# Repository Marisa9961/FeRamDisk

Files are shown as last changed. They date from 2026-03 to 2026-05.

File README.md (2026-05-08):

# FeRamDisk: 基于 STM32G431 的铁电存储 U 盘

 
 
 


## 项目概述
FeRamDisk 是一款基于 **STM32G431** 主控与 **MB85RS256** 存储介质的专用闪存盘。

不同于传统的 NAND Flash 存储方案，本项目利用铁电随机存取存储器（FeRAM）的物理特性，实现了极高的读写耐久性与近乎瞬时的随机访问能力。

硬件设计中使用了四片并列的 **MB85RS256** ，单片容量为 32 kB（即 256 Kbit），总计达到的存储空间为 128 kB。

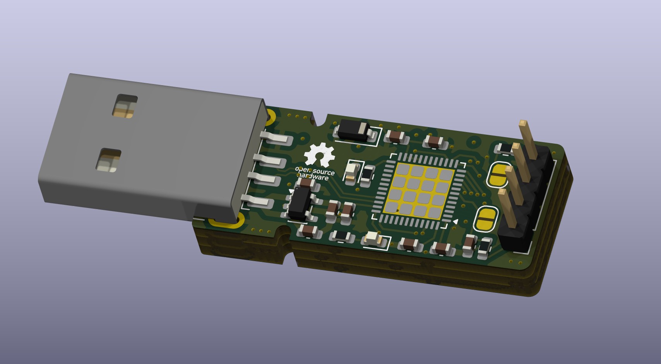
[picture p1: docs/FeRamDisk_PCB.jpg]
FeRamDisk_PCB


## 功能介绍

1. **硬件设计开源**：提供完整的 Kicad 工程、原理图及制造文件，可直接打板生产。
2. **USB 大容量存储设备固件设计**：基于 Rust embassy 异步框架，从零实现 SCSI 指令集与 BOT 协议，支持全平台免驱识别。
3. **影子存储区防止文件系统崩溃**：利用日志机制抽象存储操作，保障意外断电及插拔时的数据一致性。

## 快速上手

项目固件采用 Rust 编写。构建前请确保已安装 Rust 工具链。

```bash
cd firmware

# 编译固件（默认已启用 hardware feature）
cargo build --release

# 在主机上运行脱离硬件的单元测试（需关闭默认的硬件功能并指定主机平台）
# 另外需要根据自己的开发环境选择正确的目标平台
cargo test --no-default-features --target x86_64-pc-windows-msvc

# 如果已配置 probe-rs 等烧录工具，可直接一键编译并烧录
cargo run --release
```

## 项目构成

- `hardware/`: 硬件设计目录（包含 Kicad 源工程、BOM 表及 Gerber 生产文件）。
- `firmware/`: 核心固件目录（Rust 编写）。
  - `src/usb/`: USB 核心协议栈（MSC / BOT / SCSI）的具体实现。
  - `src/storage/`: 存储后端适配与事务日志系统（Journaling），确保块设备的高可靠读写。
  - `src/drivers/`: SPI 通信底漆及 MB85RS256 铁电存储芯片的驱动层。
  - `tests/`: 包含脱离硬件直接在 PC 端运行的协议栈软仿真测试环境。
- `docs/`: 相关的项目说明与文档资源。

## 贡献要点

欢迎任何形式的讨论与代码贡献（Pull Request / Issue）：
1. **固件开发**：PR 提交前，请确保能够通过 `tests/` 目录下的所有软仿真单元测试 (`cargo test`)。
2. **硬件优化**：如有 PCB 布局或元器件替代方案，请提供原因及 Kicad 源文件的修改。
3. **想法拓展**：欢迎探讨铁电特性（极快且无磨损限制）在微型数据记录器（Data Logger）等前沿领域的新用法。

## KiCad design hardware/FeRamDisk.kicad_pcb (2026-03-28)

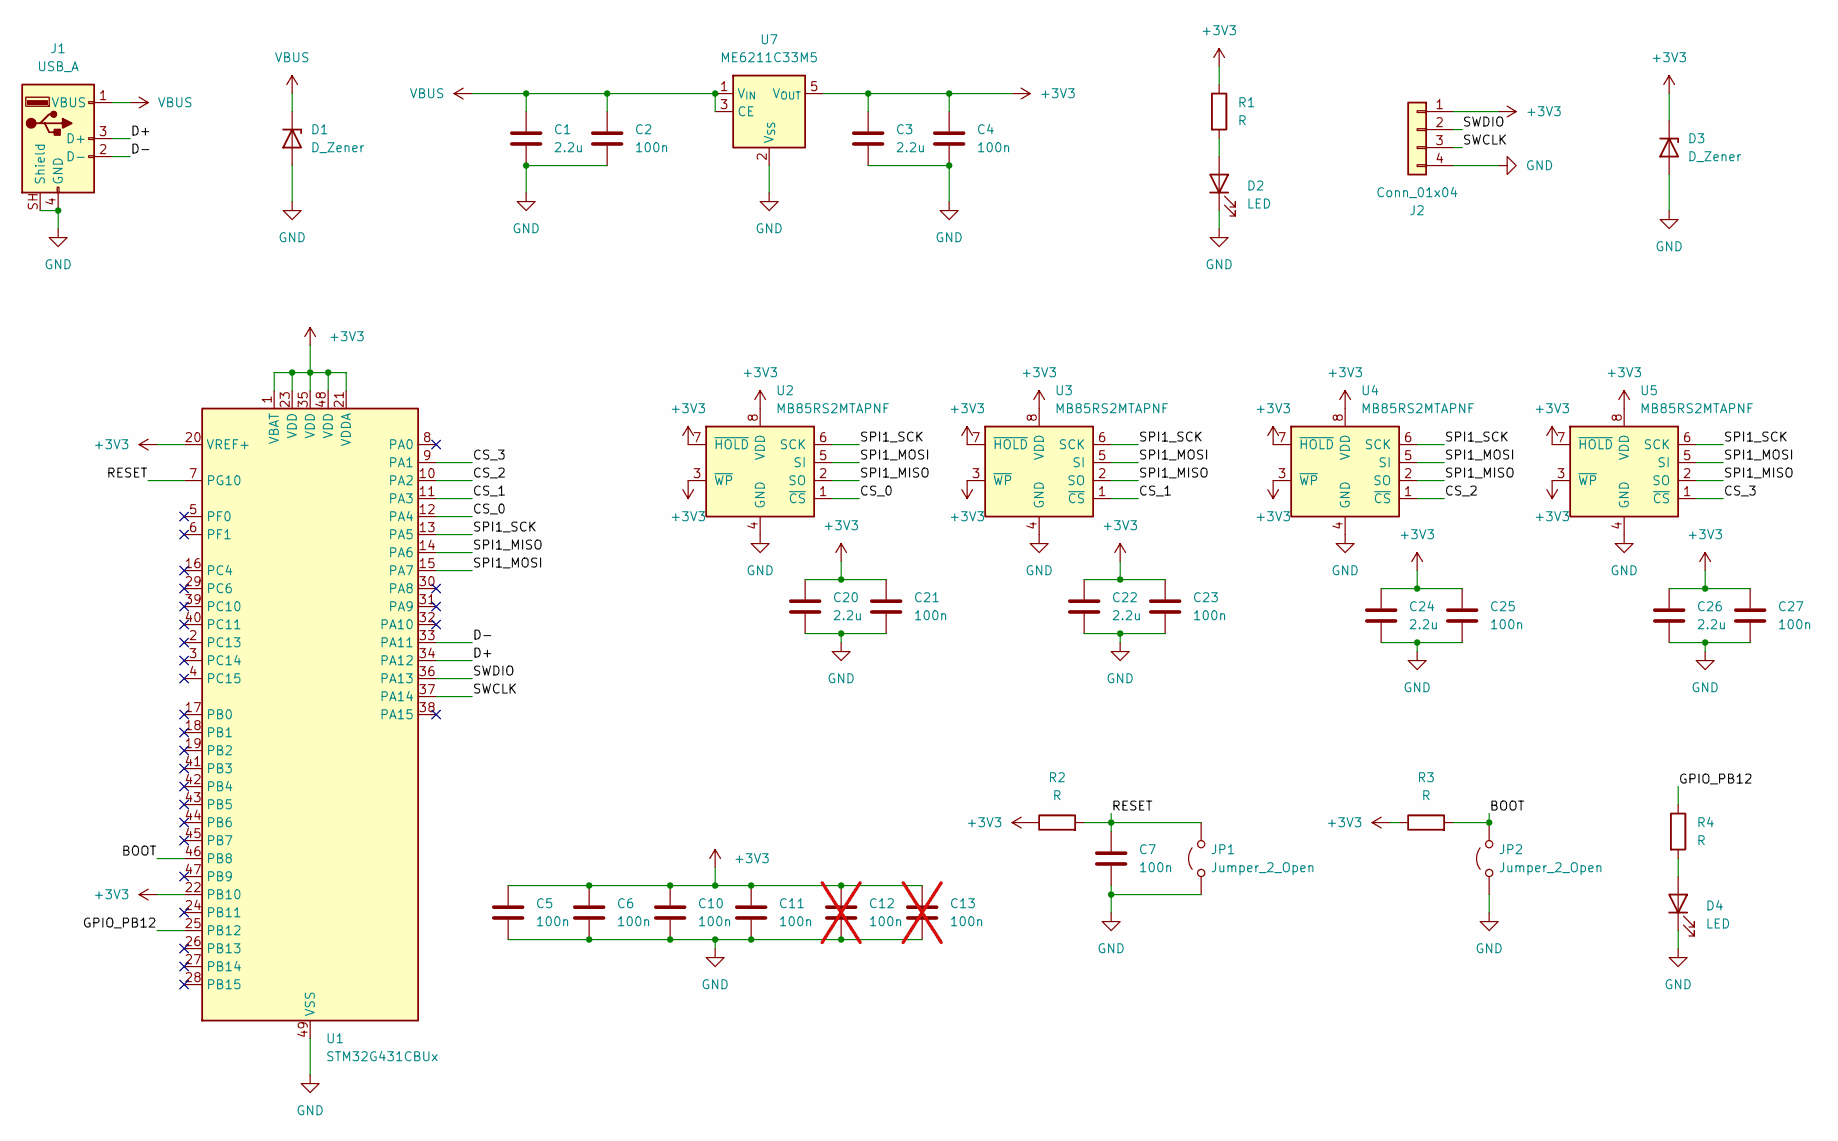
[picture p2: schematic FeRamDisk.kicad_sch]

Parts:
C1, C3, C20, C22, C24, C26: 2.2u; C_0603_1608Metric
C2, C4, C5, C6, C7, C10, C11, C21, C23, C25, C27: 100n; C_0603_1608Metric
C12, C13: 100n; C_0603_1608Metric; not fitted
D1, D3: D_Zener; D_SOD-123
D2, D4: LED; LED_0603_1608Metric
J1: USB_A; USB_A_CNCTech_1001-011-01101_Horizontal
J2: Conn_01x04; PinHeader_1x04_P2.54mm_Vertical
JP1, JP2: Jumper_2_Open; SolderJumper-2_P1.3mm_Open_RoundedPad1.0x1.5mm
R1, R2, R3, R4: R; R_0603_1608Metric
U1: STM32G431CBUx; QFN-48-1EP_7x7mm_P0.5mm_EP5.6x5.6mm
U2, U3, U4, U5: MB85RS2MTAPNF; SOP-8_3.76x4.96mm_P1.27mm
U7: ME6211C33M5; SOT-23-5

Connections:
+3V3: C3.1, C4.1, C5.1, C6.1, C10.1, C11.1, C12.1, C13.1, C20.1, C21.1, C22.1, C23.1, C24.1, C25.1, C26.1, C27.1, D3.1 (K), J2.1, R1.1, R2.1, R3.1, U1.1 (VBAT), U1.20 (VREF+), U1.21 (VDDA), U1.22 (PB10), U1.23 (VDD), U1.35 (VDD), U1.48 (VDD), U2.3 (~WP), U2.7 (~HOLD), U2.8 (VDD), U3.3 (~WP), U3.7 (~HOLD), U3.8 (VDD), U4.3 (~WP), U4.7 (~HOLD), U4.8 (VDD), U5.3 (~WP), U5.7 (~HOLD), U5.8 (VDD), U7.5 (V_{OUT})
/BOOT: JP2.2 (B), R3.2, U1.46 (PB8)
/CS_0: U1.12 (PA4), U2.1 (~CS)
/CS_1: U1.11 (PA3), U3.1 (~CS)
/CS_2: U1.10 (PA2), U4.1 (~CS)
/CS_3: U1.9 (PA1), U5.1 (~CS)
/D+: J1.3 (D+), U1.34 (PA12)
/D-: J1.2 (D-), U1.33 (PA11)
/GPIO_PB12: R4.1, U1.25 (PB12)
/RESET: C7.1, JP1.2 (B), R2.2, U1.7 (PG10)
/SPI1_MISO: U1.14 (PA6), U2.2 (SO), U3.2 (SO), U4.2 (SO), U5.2 (SO)
/SPI1_MOSI: U1.15 (PA7), U2.5 (SI), U3.5 (SI), U4.5 (SI), U5.5 (SI)
/SPI1_SCK: U1.13 (PA5), U2.6 (SCK), U3.6 (SCK), U4.6 (SCK), U5.6 (SCK)
/SWCLK: J2.3, U1.37 (PA14)
/SWDIO: J2.2, U1.36 (PA13)
GND: C1.2, C2.2, C3.2, C4.2, C5.2, C6.2, C7.2, C10.2, C11.2, C12.2, C13.2, C20.2, C21.2, C22.2, C23.2, C24.2, C25.2, C26.2, C27.2, D1.2 (A), D2.1 (K), D3.2 (A), D4.1 (K), J1.4 (GND), J1.SH (Shield), J2.4, JP1.1 (A), JP2.1 (A), U1.49 (VSS), U2.4 (GND), U3.4 (GND), U4.4 (GND), U5.4 (GND), U7.2 (V_{SS})
unnamed: D2.2 (A), R1.2
unnamed: D4.2 (A), R4.2
VBUS: C1.1, C2.1, D1.1 (K), J1.1 (VBUS), U7.1 (V_{IN}), U7.3 (CE)

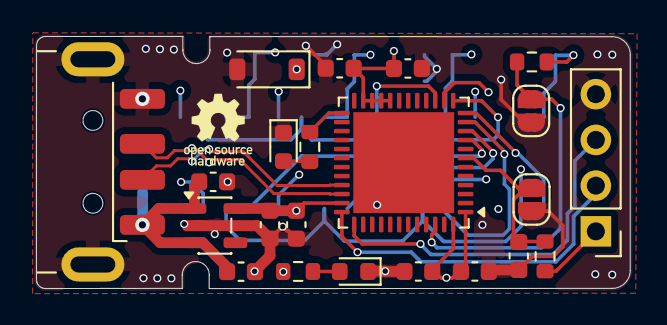
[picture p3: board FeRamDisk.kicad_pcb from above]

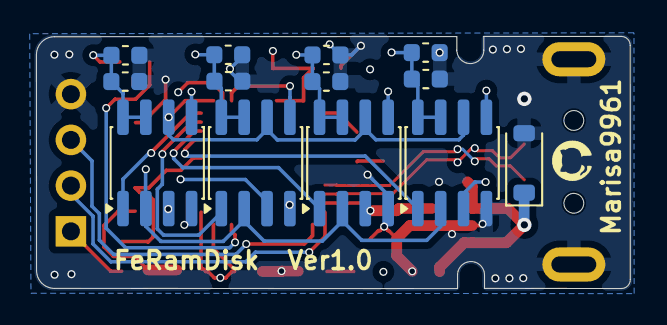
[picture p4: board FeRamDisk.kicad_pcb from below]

Board: 4 copper layers, 33.0 x 14.0 mm, 35 parts (13 on the bottom side), 19 nets.

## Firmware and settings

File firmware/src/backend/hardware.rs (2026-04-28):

use crate::drivers::feram::{self, FeRam};
use crate::drivers::spi::FramSpi;
use crate::init;
use crate::storage::{
    visible_block_count_from_physical,
    MetadataJournalStorage,
    JOURNAL_RESERVED_BLOCKS,
};
use embassy_stm32::gpio::{Level, Output, Speed};
use embassy_stm32::mode::Async;
use embassy_stm32::peripherals;
use embassy_stm32::spi::{self, mode::Master, Spi};
use embassy_stm32::time::Hertz;
use embassy_stm32::usb as stm32_usb;
use embassy_stm32::{Peri, Peripherals};
use rtt_target::rprintln;

pub type HardwareStorage = MetadataJournalStorage<
    FeRam<FramSpi<'static, Output<'static>, Output<'static>, Output<'static>, Output<'static>>>,
>;

#[derive(Debug, Copy, Clone, Eq, PartialEq)]
pub enum HardwareInitError {
    MissingResource(&'static str),
    VolumeInitFailed,
    JournalInitFailed,
}

pub struct HardwareParts {
    spi: Option<Spi<'static, Async, Master>>,
    cs0: Option<Output<'static>>,
    cs1: Option<Output<'static>>,
    cs2: Option<Output<'static>>,
    cs3: Option<Output<'static>>,
    usb: Option<Peri<'static, peripherals::USB>>,
    usb_dp: Option<Peri<'static, peripherals::PA12>>,
    usb_dm: Option<Peri<'static, peripherals::PA11>>,
}

fn spi_config() -> spi::Config {
    let mut config = spi::Config::default();
    config.frequency = Hertz(4_000_000);
    config
}

fn log_capacity(physical_blocks: u32, visible_blocks: u32) {
    rprintln!(
        "FeRAM capacity: physical={} blocks, visible={} blocks",
        physical_blocks,
        visible_blocks
    );
}

pub fn init_hardware_parts(p: Peripherals) -> HardwareParts {
    let spi = Spi::new(
        p.SPI1,
        p.PA5,
        p.PA7,
        p.PA6,
        p.DMA1_CH1,
        p.DMA1_CH2,
        init::Irqs,
        spi_config(),
    );

    let cs0 = Output::new(p.PA4, Level::High, Speed::VeryHigh);
    let cs1 = Output::new(p.PA3, Level::High, Speed::VeryHigh);
    let cs2 = Output::new(p.PA2, Level::High, Speed::VeryHigh);
    let cs3 = Output::new(p.PA1, Level::High, Speed::VeryHigh);

    HardwareParts {
        spi: Some(spi),
        cs0: Some(cs0),
        cs1: Some(cs1),
        cs2: Some(cs2),
        cs3: Some(cs3),
        usb: Some(p.USB),
        usb_dp: Some(p.PA12),
        usb_dm: Some(p.PA11),
    }
}

pub async fn init_storage(parts: &mut HardwareParts) -> Result<HardwareStorage, HardwareInitError> {
    let fram_spi = FramSpi::new(
        parts
            .spi
            .take()
            .ok_or(HardwareInitError::MissingResource("SPI already consumed"))?,
        parts
            .cs0
            .take()
            .ok_or(HardwareInitError::MissingResource("CS0 already consumed"))?,
        parts
            .cs1
            .take()
            .ok_or(HardwareInitError::MissingResource("CS1 already consumed"))?,
        parts
            .cs2
            .take()
            .ok_or(HardwareInitError::MissingResource("CS2 already consumed"))?,
        parts
            .cs3
            .take()
            .ok_or(HardwareInitError::MissingResource("CS3 already consumed"))?,
    );

    let mut fram = FeRam::new(fram_spi);
    let physical_blocks = fram.block_count();
    let visible_blocks = visible_block_count_from_physical(physical_blocks);

    log_capacity(physical_blocks, visible_blocks);

    for chip_idx in 0..feram::CHIP_COUNT {
        match fram.read_id(chip_idx).await {
            Ok(id) => {
                rprintln!(
                    "Chip {}: Device ID = 0x{:02X}{:02X}{:02X}",
                    chip_idx,
                    id[0],
                    id[1],
                    id[2]
                );
            }
            Err(e) => {
                rprintln!("Chip {}: ID read failed - {:?}", chip_idx, e);
            }
        }
    }

    match fram
        .ensure_mass_storage_volume_for_total_blocks_at_offset(visible_blocks, JOURNAL_RESERVED_BLOCKS)
        .await
    {
        Ok(true) => rprintln!("Initialized FAT12 volume for Windows"),
        Ok(false) => rprintln!("FAT12 volume already present"),
        Err(e) => {
            rprintln!("Volume initialization failed: {:?}", e);
            return Err(HardwareInitError::VolumeInitFailed);
        }
    }

    let mut storage = MetadataJournalStorage::new(fram);
    if let Err(e) = storage.initialize().await {
        rprintln!("Metadata journal initialization failed: {:?}", e);
        return Err(HardwareInitError::JournalInitFailed);
    }

    Ok(storage)
}

pub fn init_usb_driver(parts: &mut HardwareParts) -> Result<stm32_usb::Driver<'static, peripherals::USB>, HardwareInitError> {
    Ok(stm32_usb::Driver::new(
        parts
            .usb
            .take()
            .ok_or(HardwareInitError::MissingResource("USB peripheral already consumed"))?,
        init::Irqs,
        parts
            .usb_dp
            .take()
            .ok_or(HardwareInitError::MissingResource("USB DP already consumed"))?,
        parts
            .usb_dm
            .take()
            .ok_or(HardwareInitError::MissingResource("USB DM already consumed"))?,
    ))
}

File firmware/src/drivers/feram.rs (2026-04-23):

#![allow(dead_code)]

use core::cmp::min;

use crate::drivers::spi::{FramSpi, FramSpiError};
use embedded_hal::digital::OutputPin;

pub const BLOCK_SIZE: usize = crate::storage::BLOCK_SIZE;
pub const CHIP_COUNT: usize = 4;
pub const CHIP_SIZE_BYTES: usize = 32 * 1024;
pub const TOTAL_SIZE_BYTES: usize = CHIP_COUNT * CHIP_SIZE_BYTES;
pub const TOTAL_BLOCKS: u32 = (TOTAL_SIZE_BYTES / BLOCK_SIZE) as u32;

const PARTITION_START_BLOCK: u32 = 1;
const FAT_COUNT: u8 = 2;
const FAT12_MAX_CLUSTERS: u32 = 0x0FF4;
const ROOT_DIR_ENTRIES: u16 = 32;
const RESERVED_SECTORS: u16 = 1;
const PARTITION_TYPE_FAT12: u8 = 0x01;
const MEDIA_DESCRIPTOR: u8 = 0xF8;
const BOOT_OEM_NAME: &[u8; 8] = b"FRAMDISK";
const VOLUME_LABEL: &[u8; 11] = b"FERAMDISK  ";
const FILE_SYSTEM_TYPE: &[u8; 8] = b"FAT12   ";

#[derive(Copy, Clone)]
struct Fat12Geometry {
    sectors_per_cluster: u8,
    fat_sectors: u16,
    root_dir_sectors: u16,
}

const CMD_WREN: u8 = 0x06;
const CMD_WRDI: u8 = 0x04;
const CMD_RDSR: u8 = 0x05;
const CMD_WRSR: u8 = 0x01;
const CMD_READ: u8 = 0x03;
const CMD_FAST_READ: u8 = 0x0B;
const CMD_WRITE: u8 = 0x02;
const CMD_RDID: u8 = 0x9F;
const CMD_SLEEP: u8 = 0xB9;

#[derive(Debug, Copy, Clone, Eq, PartialEq)]
pub enum FeRamError<SpiError, CsError> {
    OutOfRange,
    Bus(crate::drivers::spi::FramSpiError<SpiError, CsError>),
}

pub struct FeRam<BUS> {
    bus: BUS,
}

impl<BUS> FeRam<BUS> {
    pub const fn new(bus: BUS) -> Self {
        Self { bus }
    }

    pub fn capacity_bytes(&self) -> usize {
        TOTAL_SIZE_BYTES
    }

    pub fn block_count(&self) -> u32 {
        TOTAL_BLOCKS
    }
}

impl<'d, CS0, CS1, CS2, CS3> FeRam<FramSpi<'d, CS0, CS1, CS2, CS3>>
where
    CS0: OutputPin,
    CS1: OutputPin<Error = CS0::Error>,
    CS2: OutputPin<Error = CS0::Error>,
    CS3: OutputPin<Error = CS0::Error>,
{
    pub async fn read(
        &mut self,
        address: usize,
        out: &mut [u8],
    ) -> Result<(), FeRamError<embassy_stm32::spi::Error, CS0::Error>> {
        self.check_range(address, out.len())?;

        let mut remaining = out;
        let mut current_addr = address;

        while !remaining.is_empty() {
            let chip = current_addr / CHIP_SIZE_BYTES;
            let chip_addr = (current_addr % CHIP_SIZE_BYTES) as u32;
            let chunk_len = min(CHIP_SIZE_BYTES - (current_addr % CHIP_SIZE_BYTES), remaining.len());

            let (chunk, tail) = remaining.split_at_mut(chunk_len);
            self.read_on_chip(chip, chip_addr, chunk).await?;

            current_addr += chunk_len;
            remaining = tail;
        }

        Ok(())
    }

    pub async fn fast_read(
        &mut self,
        address: usize,
        out: &mut [u8],
    ) -> Result<(), FeRamError<embassy_stm32::spi::Error, CS0::Error>> {
        self.check_range(address, out.len())?;

        let mut remaining = out;
        let mut current_addr = address;

        while !remaining.is_empty() {
            let chip = current_addr / CHIP_SIZE_BYTES;
            let chip_addr = (current_addr % CHIP_SIZE_BYTES) as u32;
            let chunk_len = min(CHIP_SIZE_BYTES - (current_addr % CHIP_SIZE_BYTES), remaining.len());

            let (chunk, tail) = remaining.split_at_mut(chunk_len);
            self.fast_read_on_chip(chip, chip_addr, chunk).await?;

            current_addr += chunk_len;
            remaining = tail;
        }

        Ok(())
    }

    pub async fn write(
        &mut self,
        address: usize,
        data: &[u8],
    ) -> Result<(), FeRamError<embassy_stm32::spi::Error, CS0::Error>> {
        self.check_range(address, data.len())?;

        let mut remaining = data;
        let mut current_addr = address;

        while !remaining.is_empty() {
            let chip = current_addr / CHIP_SIZE_BYTES;
            let chip_addr = (current_addr % CHIP_SIZE_BYTES) as u32;
            let chunk_len = min(CHIP_SIZE_BYTES - (current_addr % CHIP_SIZE_BYTES), remaining.len());

            let (chunk, tail) = remaining.split_at(chunk_len);
            self.write_on_chip(chip, chip_addr, chunk).await?;

            current_addr += chunk_len;
            remaining = tail;
        }

        Ok(())
    }

    pub async fn read_block(
        &mut self,
        block_index: u32,
        out: &mut [u8; BLOCK_SIZE],
    ) -> Result<(), FeRamError<embassy_stm32::spi::Error, CS0::Error>> {
        self.read(block_index as usize * BLOCK_SIZE, out).await
    }

    pub async fn write_block(
        &mut self,
        block_index: u32,
        data: &[u8; BLOCK_SIZE],
    ) -> Result<(), FeRamError<embassy_stm32::spi::Error, CS0::Error>> {
        self.write(block_index as usize * BLOCK_SIZE, data).await
    }

    pub async fn ensure_mass_storage_volume(
        &mut self,
    ) -> Result<bool, FeRamError<embassy_stm32::spi::Error, CS0::Error>> {
        self.ensure_mass_storage_volume_for_total_blocks(TOTAL_BLOCKS).await
    }

    pub async fn ensure_mass_storage_volume_for_total_blocks(
        &mut self,
        total_blocks: u32,
    ) -> Result<bool, FeRamError<embassy_stm32::spi::Error, CS0::Error>> {
        self.ensure_mass_storage_volume_for_total_blocks_at_offset(total_blocks, 0)
            .await
    }

    pub async fn ensure_mass_storage_volume_for_total_blocks_at_offset(
        &mut self,
        total_blocks: u32,
        volume_start_block: u32,
    ) -> Result<bool, FeRamError<embassy_stm32::spi::Error, CS0::Error>> {
        if total_blocks <= PARTITION_START_BLOCK || total_blocks > TOTAL_BLOCKS {
            return Err(FeRamError::OutOfRange);
        }

        let end_block = volume_start_block
            .checked_add(total_blocks)
            .ok_or(FeRamError::OutOfRange)?;
        if end_block > TOTAL_BLOCKS {
            return Err(FeRamError::OutOfRange);
        }

        let partition_blocks = total_blocks - PARTITION_START_BLOCK;
        let geometry = calculate_fat12_geometry(partition_blocks);

        if self
            .has_valid_volume_layout(volume_start_block, partition_blocks, geometry)
            .await?
        {
            return Ok(false);
        }

        self.format_mass_storage_volume(volume_start_block, partition_blocks, geometry)
            .await?;
        Ok(true)
    }

    async fn has_valid_volume_layout(
        &mut self,
        volume_start_block: u32,
        partition_blocks: u32,
        geometry: Fat12Geometry,
    ) -> Result<bool, FeRamError<embassy_stm32::spi::Error, CS0::Error>> {
        let mut mbr = [0u8; BLOCK_SIZE];
        self.read_block(volume_start_block, &mut mbr).await?;

        if mbr[510] != 0x55 || mbr[511] != 0xAA {
            return Ok(false);
        }

        let partition = &mbr[446..462];
        if partition[4] != PARTITION_TYPE_FAT12 {
            return Ok(false);
        }

        if u32::from_le_bytes([partition[8], partition[9], partition[10], partition[11]]) != PARTITION_START_BLOCK {
            return Ok(false);
        }
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

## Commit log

2026-03-28 feat: hardware version 1.0
    [FeRamDisk.kicad_pcb, FeRamDisk.kicad_sch]
2026-03-28 feat: initialize framework
2026-04-02 feat: add embassy framework
2026-04-15 fix: slow spi rate; add chip id check
2026-04-16 feat: improve msc.rs and device.rs for stability
2026-04-28 fix: improve protocol stack compliance and error resilience; expand test coverage
    [hardware.rs]
